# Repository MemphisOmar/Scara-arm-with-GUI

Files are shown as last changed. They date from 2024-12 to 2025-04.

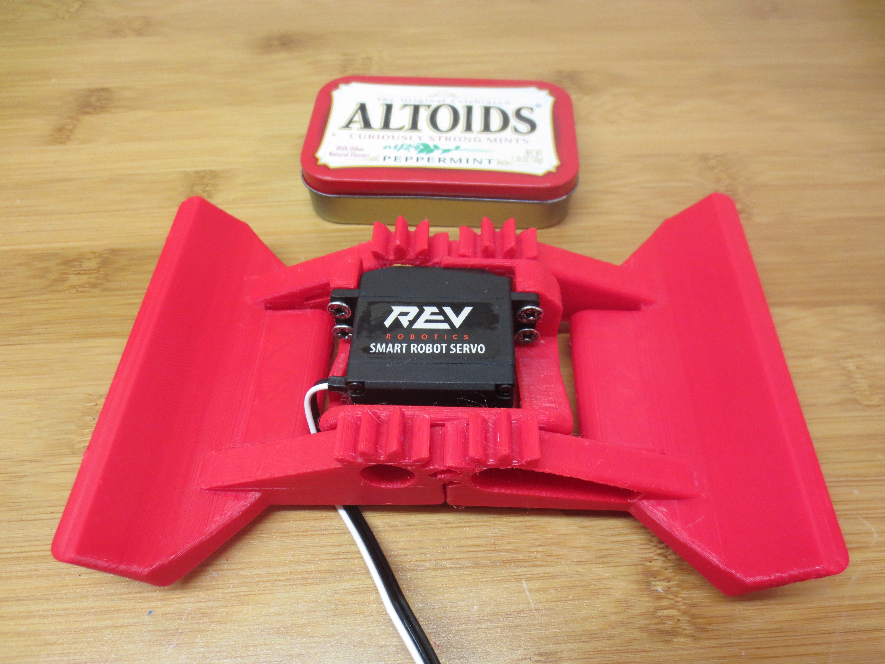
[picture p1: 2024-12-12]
SCARA_CAD/GRIPPER/images/IMG_7482.JPG

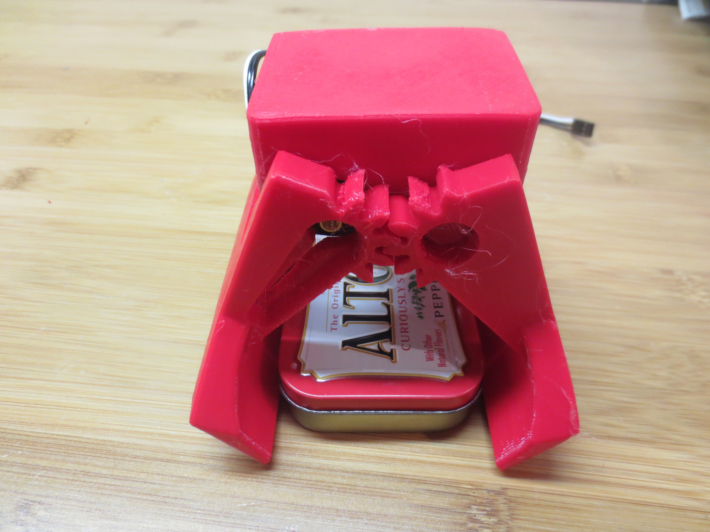
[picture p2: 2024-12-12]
SCARA_CAD/GRIPPER/images/IMG_7483.JPG

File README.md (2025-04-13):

# SCARA Robotic Arm with Graphical Interface

## GRAPHICAL INTERFACE

The graphical interface was programmed in Python using the Flet framework. It is a dynamic interface that communicates with the application via serial communication, displaying real-world changes in the application.

On the left side, the interface features two 2x2 matrices. When a cube is placed in a designated spot within these matrices, the corresponding indicator light for that cube position will illuminate.

The process will automatically pause once both matrices are filled. The operator must then manually restart the process.

A central indicator displays whether the currently detected cube is "Defective" or "Valid". Below this indicator, simple control buttons with essential functions are provided: START, Pause, Continue, and Restart.



## SOLIDWORKS ASSEMBLY



## ASSEMBLED ROBOT

The microcontroller has two initial conditions. The first is the I2C address of the RGB sensor, which is used for the homing procedure.

Once the homing sequence is complete, the graphical interface needs to send a "START" command to initiate the detection process.

The robot's direct kinematics have been solved to allow for individual joint movement in degrees. This facilitates easier access and modification of specific points. The robot is programmed to visit nine key locations: the eight positions corresponding to the cube locations within the two matrices, and one final position on the conveyor belt for placing the valid cubes. To achieve this, the position vectors for each desired location are calculated and stored within the robot's control code.

If a cube is determined to be valid, the robot will retrieve it from the end of the conveyor belt and place it in its designated spot within the matrix. If a cube is defective, the robot will not proceed until the defective cube is removed and a valid cube arrives. This entire process is managed using simple boolean flags within the control logic.




## INTERFACE IN OPERATION




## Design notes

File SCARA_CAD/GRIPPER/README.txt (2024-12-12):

20 kg·cm Robotic Gripper by MechEngineerMike on Thingiverse: https://www.thingiverse.com/thing:3041971

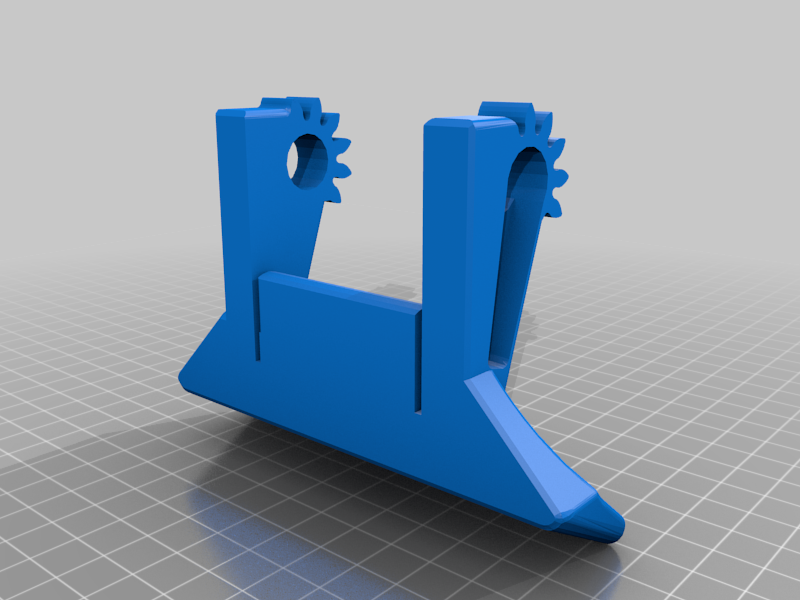
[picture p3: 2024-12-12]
SCARA_CAD/GRIPPER/images/e842a4ac5647148de83dd07140da1f07.png

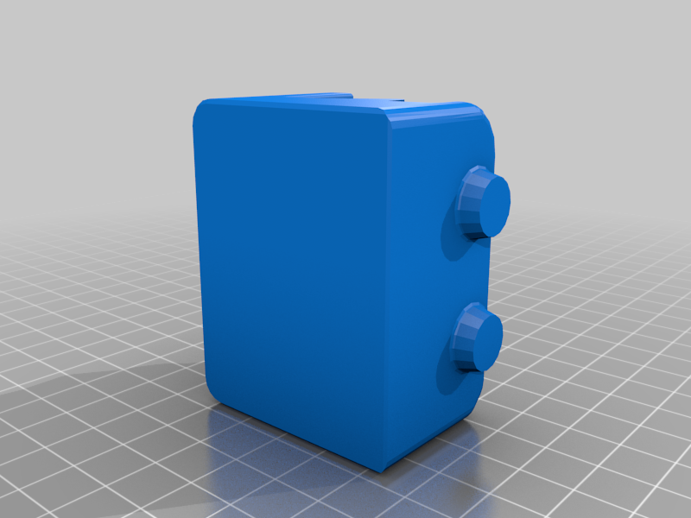
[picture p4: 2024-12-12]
SCARA_CAD/GRIPPER/images/df90dd607aa34544be3c17018d071d21.png

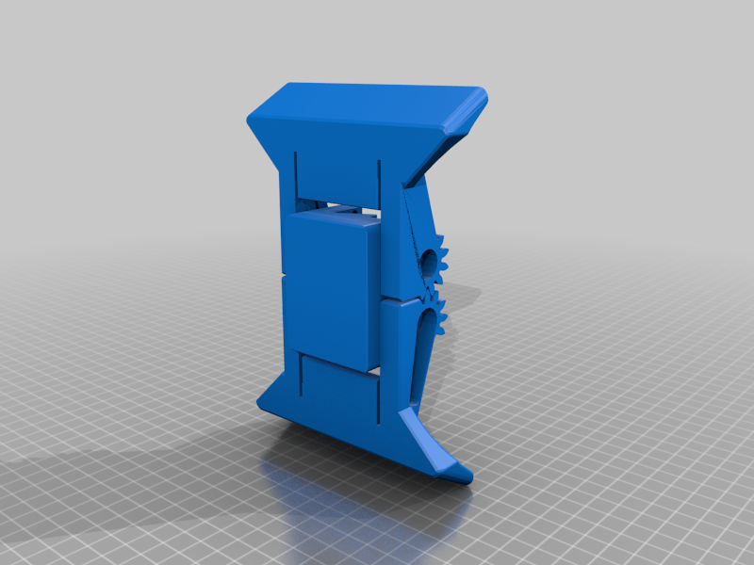
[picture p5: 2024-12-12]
SCARA_CAD/GRIPPER/images/337ccc582f414baa7ae840020906a578.png

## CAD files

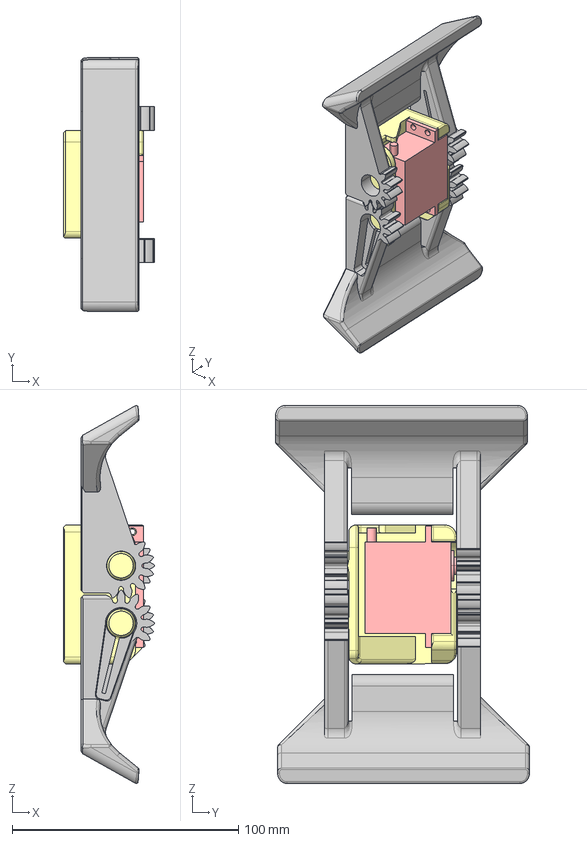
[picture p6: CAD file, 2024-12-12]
SCARA_CAD/GRIPPER/files/Assy_Gripper_20KGcm.stp
40.1 x 112.3 x 167.1 mm
servo_SG90
Arm_Gripper_WIDE x 2
horn.1.1
Gripper_Mount.2

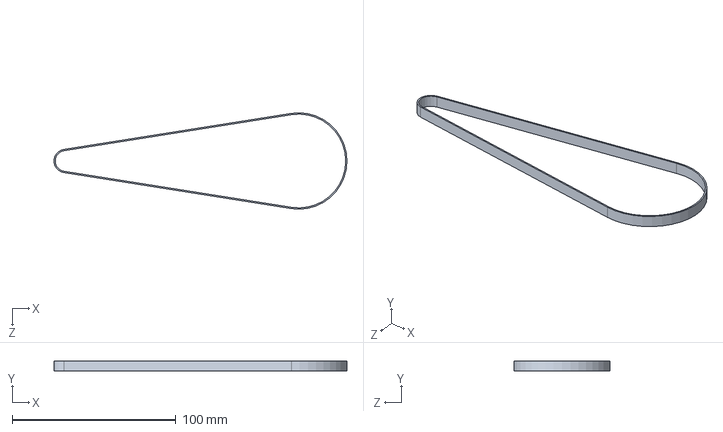
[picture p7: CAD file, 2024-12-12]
SCARA_CAD/GT2 Belt 400mm 2.SLDPRT
179.0 x 6.00 x 58.9 mm

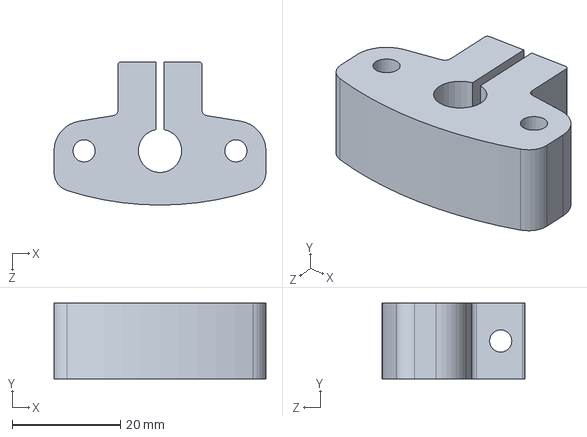
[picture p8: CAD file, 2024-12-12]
SCARA_CAD/11-SOPORTEVARILLA.SLDPRT
39.1 x 14.0 x 26.4 mm

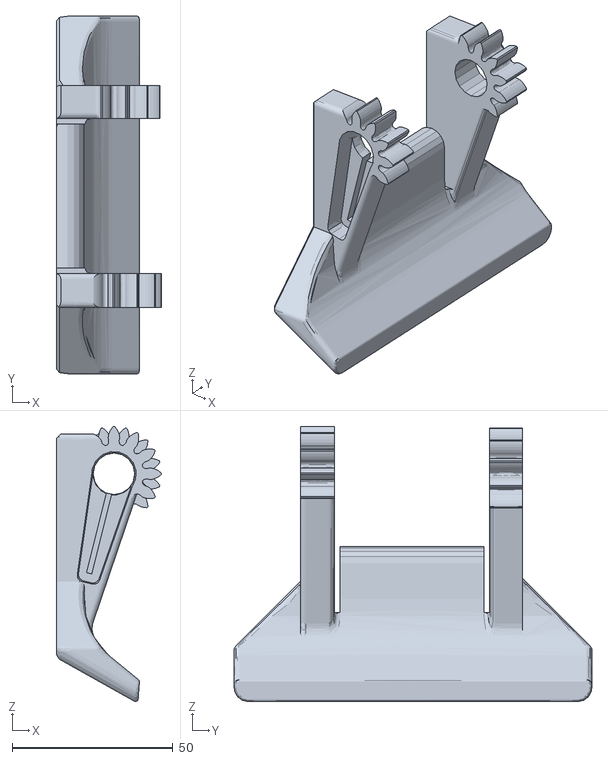
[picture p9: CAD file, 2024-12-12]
SCARA_CAD/GRIPPER/files/Gearheads-gripper-arm.stl
32.5 x 111.4 x 85.5

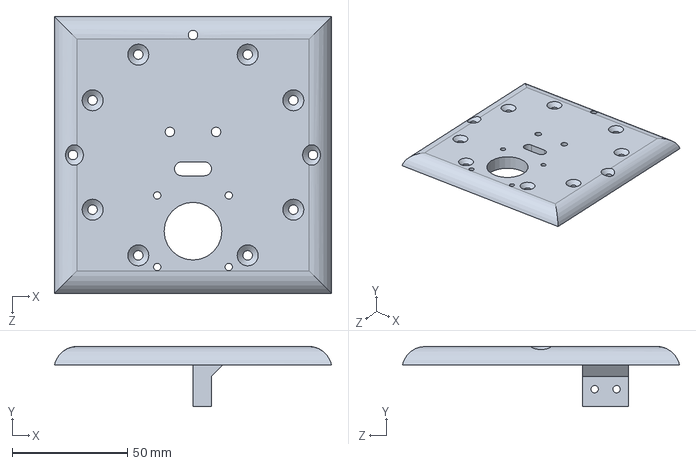
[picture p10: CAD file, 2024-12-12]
SCARA_CAD/10-TOPZ.SLDPRT
120.0 x 26.0 x 120.0 mm

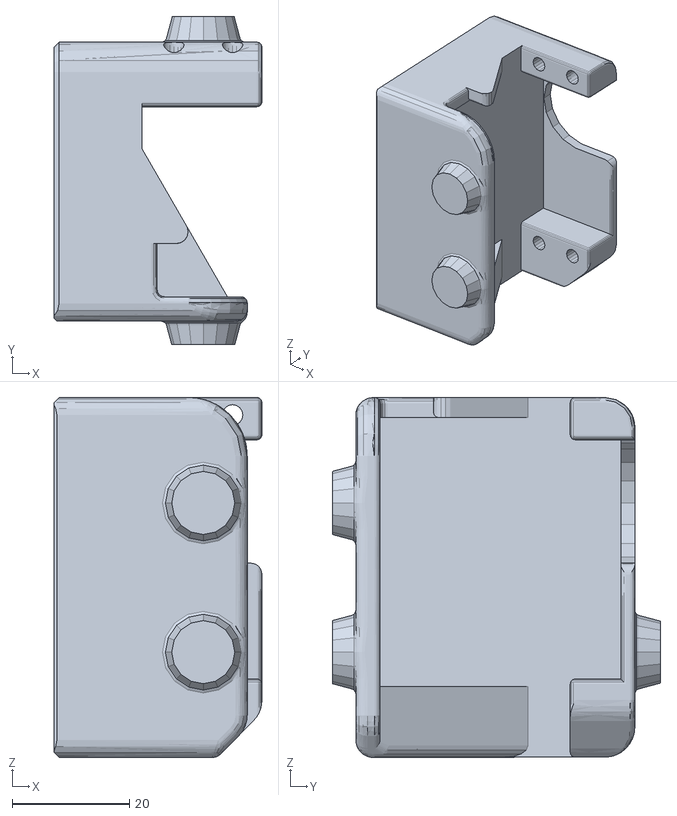
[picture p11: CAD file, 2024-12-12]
SCARA_CAD/GRIPPER/files/gearheads-gripper-mount.stl
35.4 x 56.0 x 61.3

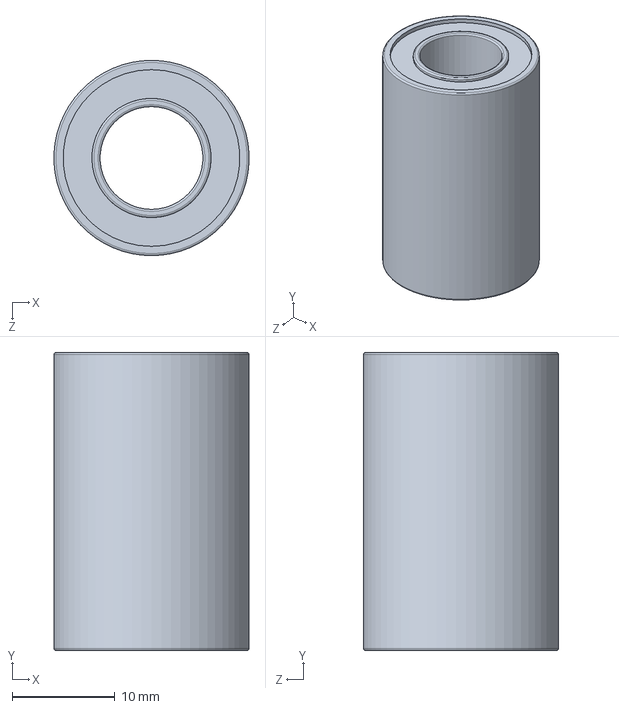
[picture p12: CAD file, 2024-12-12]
SCARA_CAD/Linear Bearing 10x19x29mm.SLDPRT
19.0 x 29.0 x 19.0 mm

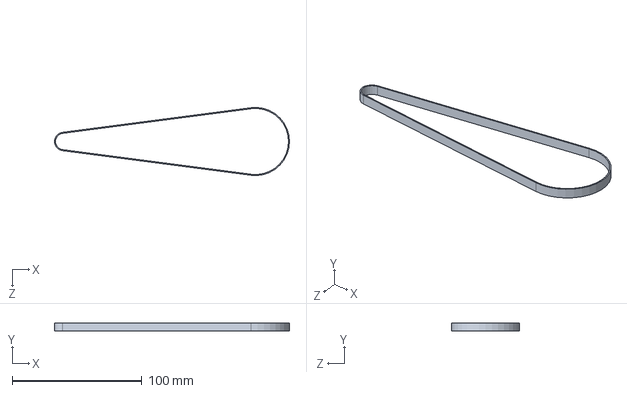
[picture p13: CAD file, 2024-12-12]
SCARA_CAD/GT2 Belt 400mm.SLDPRT
181.4 x 6.00 x 52.5 mm

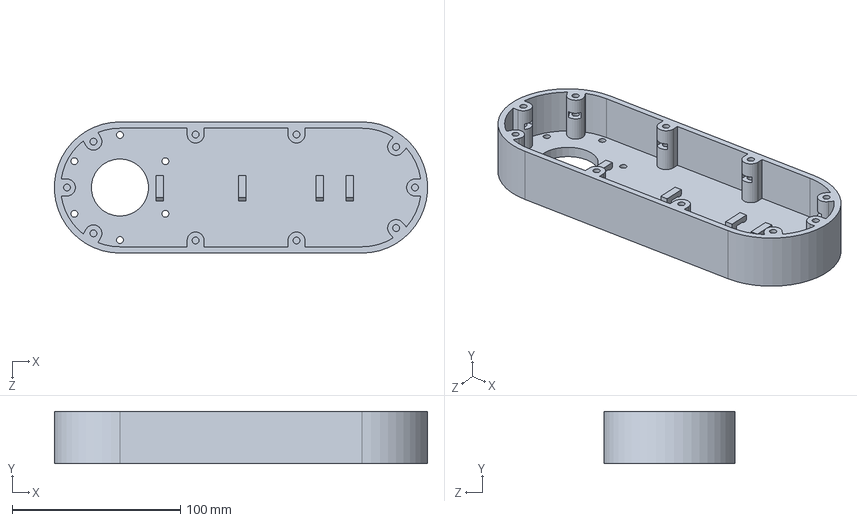
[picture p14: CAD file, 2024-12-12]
SCARA_CAD/6-J2BRZO.SLDPRT
221.8 x 31.0 x 78.0 mm

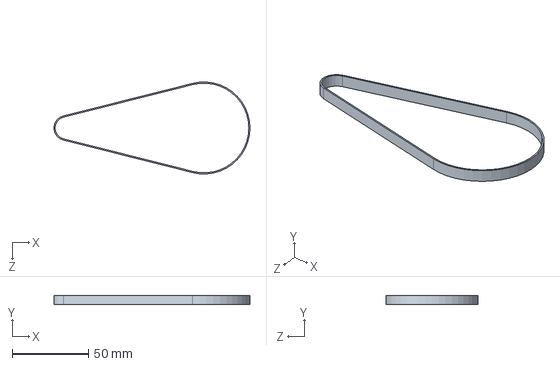
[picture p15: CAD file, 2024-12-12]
SCARA_CAD/GT2 Belt 300mm.SLDPRT
128.1 x 6.00 x 60.1 mm

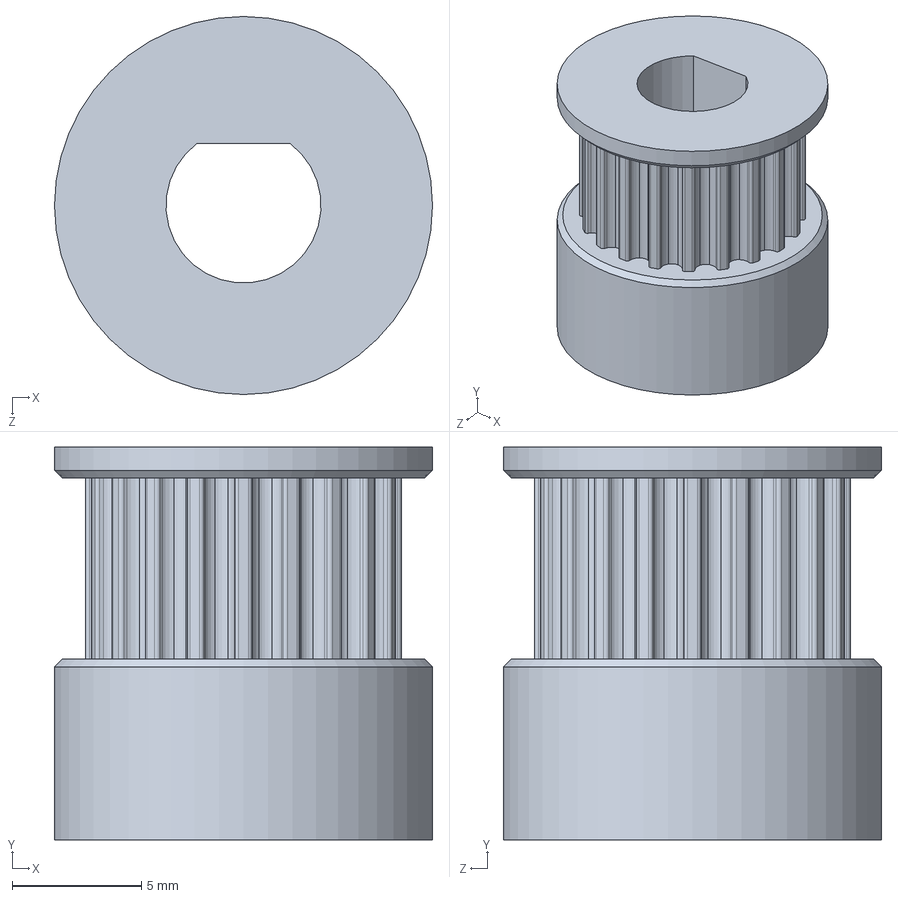
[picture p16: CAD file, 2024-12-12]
SCARA_CAD/GT2 Pulley - Parametric.SLDPRT
14.6 x 15.2 x 14.6 mm

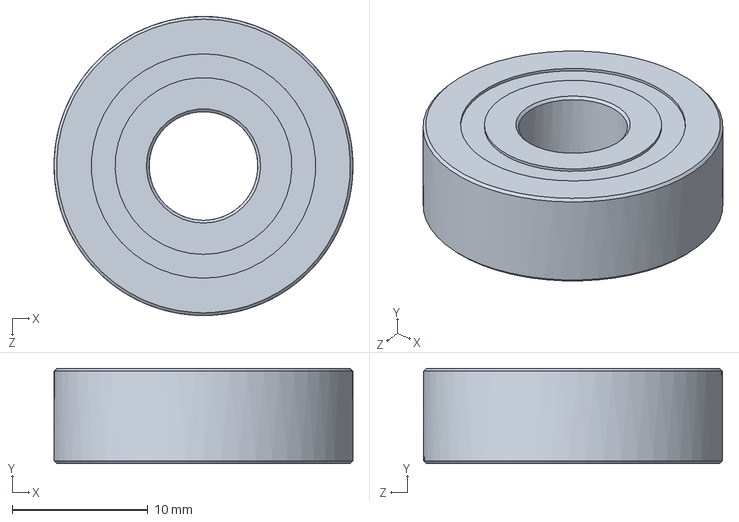
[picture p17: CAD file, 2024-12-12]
SCARA_CAD/Ball Bearing 608 - 8x22x7mm.SLDPRT
22.0 x 7.00 x 22.0 mm

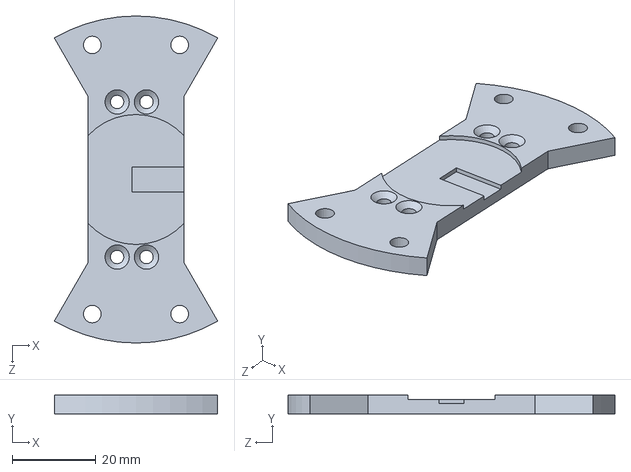
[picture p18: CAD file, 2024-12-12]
SCARA_CAD/9-UNIONPARAJ3.SLDPRT
39.0 x 4.50 x 78.0 mm

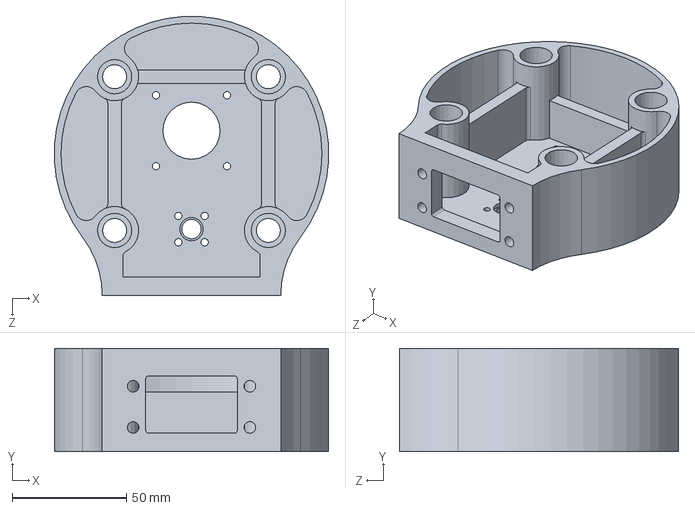
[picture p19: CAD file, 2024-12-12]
SCARA_CAD/3-J1CENTRAL.SLDPRT
119.8 x 45.0 x 121.9 mm

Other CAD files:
SCARA_CAD/Thrust Bearing 35x52x12mm.SLDPRT
SCARA_CAD/Ball Bearing 35x47x7mm.SLDPRT
SCARA_CAD/Micro switch.SLDPRT
SCARA_CAD/Smooth Rod D10mm L400mm.SLDPRT
SCARA_CAD/0-Base.SLDPRT
SCARA_CAD/1-J1 ACOPLEMOD.SLDPRT
SCARA_CAD/2-TapaZ.SLDPRT
SCARA_CAD/4-J1CENTRALBRAZO.SLDPRT
SCARA_CAD/5-COPLEJ1J2.SLDPRT
SCARA_CAD/7-J2TAPABRZO.SLDPRT
SCARA_CAD/8-J3COPLE.SLDPRT
SCARA_CAD/Ball Bearing 30x42x7mm.SLDPRT
SCARA_CAD/GT2 Belt 200mm.SLDPRT
SCARA_CAD/GT2 Belt 300mm 2.SLDPRT
SCARA_CAD/Lead Screw D8mm L380mm.SLDPRT
SCARA_CAD/Lead Screw Nut 8mm.SLDPRT
SCARA_CAD/Stepper NEMA 17 - 20mm shaft.SLDPRT
SCARA_CAD/Thrust Bearing - 40x60x13.SLDPRT
SCARA_CAD/gearheads-gripper-mount.SLDPRT

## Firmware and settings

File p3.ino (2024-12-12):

#include <AccelStepper.h>
#include <Servo.h> ///////////pendiente gripper
#include <math.h>
#include <TimerOne.h>
#include <Wire.h>
#include <Adafruit_TCS34725.h>
Adafruit_TCS34725 tcs = Adafruit_TCS34725(TCS34725_INTEGRATIONTIME_50MS, TCS34725_GAIN_4X);
unsigned long previousMillis = 0; // Para almacenar el último tiempo en que se ejecutó printVal
const long interval = 1000;
#define limitSwitch1 11
#define limitSwitch2 10
#define limitSwitch3 A3
#define limitSwitch4 9

#define motorPin1 36
#define motorPin2 37
#define sensorInicial 45
#define sensorFinal 47
#define servoPin 49
AccelStepper stepper1(1, 2, 5); // (driver, STEP, DIR)
AccelStepper stepper2(1, 3, 6);
AccelStepper stepper3(1, 4, 7); //////// PENDIENTE GRIPPER
AccelStepper stepper4(1, 12, 13);
Servo gripperServo; 
Servo conveyorServo;

// Puntos en grados
int conveyorBeltPosition[4] = {10, 23, 0, 120}; // Banda transportadora en grados
const int numPoints = 8;
int points[numPoints][4] = {
  {0, 105, 0, 85}, // Punto 1 en grados
  {4, 115, 0, 85}, // Punto 2 en grados
  {-10, 130, 0, 85}, // Punto 3 en grados
  {-8, 115, 0, 85}, // Punto 4 en grados
  {0, 105, 0, 100}, // Punto 5 en grados
  {4, 115, 0, 100}, // Punto 6 en grados
  {-10, 130, 0, 100}, // Punto 7 en grados
  {-8, 115, 0, 100}  // Punto 8 en grados
};

double x = 10.0;
double y = 10.0;
double L1 = 228; // L1 = 228mm
double L2 = 136.5; // L2 = 136.5mm
double theta1, theta2, phi, z;

int stepper1Position, stepper2Position, stepper3Position, stepper4Position;

const float theta1AngleToSteps = 44.444444;
const float theta2AngleToSteps = 35.555555;
const float phiAngleToSteps = 10;
const float zDistanceToSteps = 100;

byte inputValue[5];
int k = 0;
bool paused = false;
bool startCommandReceived = false;
bool stopCommandReceived = false;
String content = "";
int data[10];

int theta1Array[100];
int theta2Array[100];
int phiArray[100];
int zArray[100];
int gripperArray[100];
int positionsCounter = 0;

volatile bool OBJVAL = false;
volatile bool toggle = false; // Declarar toggle como variable global

void setup() {
  Serial.begin(115200);

  if (tcs.begin()) {
    Serial.println("Sensor TCS34725 iniciado correctamente.");
  } else {
    Serial.println("Error al iniciar el sensor TCS34725. Verifique la conexión.");
    while (1); // Detener el programa si no se puede iniciar el sensor
  }

  pinMode(limitSwitch1, INPUT_PULLUP);
  pinMode(limitSwitch2, INPUT_PULLUP);
  pinMode(limitSwitch3, INPUT_PULLUP);
  pinMode(limitSwitch4, INPUT_PULLUP);

  // Stepper motors max speed
  stepper1.setMaxSpeed(4000);
  stepper1.setAcceleration(2000);
  stepper2.setMaxSpeed(4000);
  stepper2.setAcceleration(2000);
  stepper3.setMaxSpeed(4000);
  stepper3.setAcceleration(2000);
  stepper4.setMaxSpeed(4000);
  stepper4.setAcceleration(2000);
  
  gripperServo.attach(53, 600, 2500);
  data[6] = 100;
  gripperServo.write(data[6]);
  conveyorServo.write(180); // Posición inicial del servo


  delay(1000);
  data[5] = 100;
  homing();


  digitalWrite(motorPin1, HIGH);
  digitalWrite(motorPin2, LOW);
}

void loop() {
   static unsigned long lastSensorReadTime = 0;
  const unsigned long sensorReadInterval = 1000;
  motorAdelante();
  // Esperar el comando "START" para iniciar
  if (!startCommandReceived || stopCommandReceived) {
    if (Serial.available() > 0) {
      String command = Serial.readStringUntil('\n');
      command.trim();
      if (command == "START") {
        startCommandReceived = true;
        stopCommandReceived = false;
        Serial.println("SISTEMA INICIADO");
      } else if (command == "STOP") {
        startCommandReceived = false;
        stopCommandReceived = true;
        Serial.println("SISTEMA DETENIDO");
      }
    }
    return; // No hacer nada hasta recibir el comando "START"
  }

  // Leer valores del sensor RGB periódicamente
  if (millis() - lastSensorReadTime >= sensorReadInterval) {
    lastSensorReadTime = millis();
    uint16_t r, g, b, c;
    tcs.getRawData(&r, &g, &b, &c);

    // Normalizar los valores RGB
    float sum = r + g + b;
    float red = r / sum;
    float green = g / sum;

    // Clasificar el color
    if (red > green && red > 0.45) {
      Serial.println("DEF");
      OBJVAL = false;
      conveyorServo.write(125); // Activar el servo para el cubo defectuoso
    } else if (green > red && green > 0.45) {
      Serial.println("VAL");
      conveyorServo.write(180); // Activar el servo para el cubo defectuoso
      OBJVAL = true;
    }
  }

  // Resto del código del bucle
  for (int i = 0; i < numPoints; i++) {
    // Esperar a que OBJVAL sea true para procesar el cubo
    while (!OBJVAL) {
      // Leer valores del sensor RGB periódicamente
      if (millis() - lastSensorReadTime >= sensorReadInterval) {
        lastSensorReadTime = millis();
        uint16_t r, g, b, c;
        tcs.getRawData(&r, &g, &b, &c);

        // Normalizar los valores RGB
        float sum = r + g + b;
        float red = r / sum;
        float green = g / sum;

        // Clasificar el color
        if (red > green && red > 0.45) {
          Serial.println("DEF");
          OBJVAL = false;
          conveyorServo.write(180); // Activar el servo para el cubo defectuoso
        } else if (green > red && green > 0.45) {
          Serial.println("VAL");
          OBJVAL = true;
          conveyorServo.write(125); // Activar el servo para el cubo defectuoso
        }
      }
      delay(100); // Espera un poco antes de verificar nuevamente
    }

    // Mover a la banda transportadora
    moveToPosition(conveyorBeltPosition);
    delay(1000); // Espera un segundo antes de tomar el cubo

    // Simular la acción de tomar el cubo
    gripperServo.write(180); // Cerrar el gripper
    delay(500); // Espera medio segundo para asegurar que el cubo está tomado
    moveToSafeZ();
    delay(100);
    // Mover al punto de destino
    moveToPosition(points[i]);
    delay(1000); 
    gripperServo.write(90); // Abrir el gripper
    delay(500); 
    Serial.print("P");
    Serial.println(i + 1);

    // Cambiar la bandera a false después de procesar el cubo
    OBJVAL = false;
    moveToSafeZ();
    delay(100);
    // Verificar si se debe pausar
    while (paused) {
      if (Serial.available() > 0) {
        String command = Serial.readStringUntil('\n');
        command.trim();
        if (command.equals("CONTINUAR")) {
          paused = false;
          Serial.println("CONTINUAO");
        }
      }
    }

    // Verificar si se debe pausar después de cada punto
    if (Serial.available() > 0) {
      String command = Serial.readStringUntil('\n');
      command.trim();
      if (command.equals("PAUSAR")) {
        paused = true;
        Serial.println("PAUSAO");
      }
    }
  }

  // Pausar al llegar al último punto y esperar el comando "REINICIAR"
  while (true) {
    if (Serial.available() > 0) {
      String command = Serial.readStringUntil('\n');
      command.trim();
      if (command.equals("REINICIAR")) {
        break;
      }
    }
  }
}

void moveToPosition(int point[4]) {
  stepper1.moveTo(point[0] * theta1AngleToSteps);
  stepper2.moveTo(point[1] * theta2AngleToSteps);
  stepper3.moveTo(point[2] * phiAngleToSteps);
  stepper4.moveTo(point[3] * zDistanceToSteps);

  while (stepper1.distanceToGo() != 0 || 
         stepper2.distanceToGo() != 0 || 
         stepper3.distanceToGo() != 0 || 
         stepper4.distanceToGo() != 0) {
    stepper1.run();
    stepper2.run();
    stepper3.run();
    stepper4.run();
  }
}

void serialFlush() {
  while (Serial.available() > 0) {
    Serial.read();
  }
}

void moveToSafeZ() {
  stepper4.moveTo(165 * zDistanceToSteps);
  while (stepper4.distanceToGo() != 0) {
    stepper4.run();
  }
}

void homing() {
  // Homing Stepper4
  while (digitalRead(limitSwitch4) != 0) {
    stepper4.setSpeed(1500);
    stepper4.runSpeed();
    stepper4.setCurrentPosition(17000); // When limit switch pressed set position to 0 steps
  }
  delay(20);
  stepper4.moveTo(16500);
  while (stepper4.currentPosition() !=16500) {
    stepper4.run();
  }

  stepper3.moveTo(0);
  while (stepper3.currentPosition() != 0) {
    stepper3.run();
  }

  // Homing Stepper2
  while (digitalRead(limitSwitch2) != 0) {
    stepper2.setSpeed(-1300);
    stepper2.runSpeed();
    stepper2.setCurrentPosition(-5420); // When limit switch pressed set position to -5440 steps
  }
  delay(20);

  stepper2.moveTo(0);
  while (stepper2.currentPosition() != 0) {
    stepper2.run();
  }

  // Homing Stepper1
  while (digitalRead(limitSwitch1) != 0) {
    stepper1.setSpeed(-1200);
    stepper1.runSpeed();
    stepper1.setCurrentPosition(-3955); // When limit switch pressed set position to 0 steps
  }
  delay(20);
  stepper1.moveTo(0);
  while (stepper1.currentPosition() != 0) {
    stepper1.run();
  }
}




void motorAdelante() {
  digitalWrite(motorPin1, HIGH);
  digitalWrite(motorPin2, LOW);
}

void motorParar() {
  digitalWrite(motorPin1, LOW);
  digitalWrite(motorPin2, LOW);
}

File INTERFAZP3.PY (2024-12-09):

import flet as ft
import serial
import threading

# Configuración del puerto serial
ser = serial.Serial('COM3', 115200, timeout=1)  # Añadir timeout para evitar bloqueos

# Función para leer datos del puerto serial
def read_serial(leds, text_display, pause_button, reiniciar_button, led_indicator, start_button, status_led):
    while True:
        if ser.in_waiting > 0:
            data = ser.readline().decode('utf-8').strip()
            print(f"Received: {data}")  # Mensaje de depuración
            text_display.value = data
            text_display.update()
            if data == "REINICIAR":
                for led in leds:
                    led.bgcolor = ft.colors.BLACK
                    led.update()
            elif data.startswith("P") and data[1:].isdigit():
                index = int(data[1]) - 1
                if 0 <= index < len(leds):
                    leds[index].bgcolor = ft.colors.GREEN
                    leds[index].update()
            elif data == "PAUSAO":
                pause_button.text = "CONTINUAR"
                led_indicator.bgcolor = ft.colors.RED
                pause_button.update()
                led_indicator.update()
            elif data == "CONTINUAO":
                pause_button.text = "PAUSAR"
                led_indicator.bgcolor = ft.colors.GREEN
                pause_button.update()
                led_indicator.update()
            elif data == "VAL":
                print("VAL received")  # Mensaje de depuración
                status_led.bgcolor = ft.colors.GREEN
                status_led.content = ft.Text("VALIDO", color=ft.colors.WHITE, size=60)  # Ajustar el tamaño del texto
                status_led.update()
            elif data == "DEF":
                print("DEF received")  # Mensaje de depuración
                status_led.bgcolor = ft.colors.RED
                status_led.content = ft.Text("DEFECTUOSO", color=ft.colors.WHITE, size=60)  # Ajustar el tamaño del texto
                status_led.update()
            
            # Verificar si todos los LEDs están encendidos
            all_on = all(led.bgcolor == ft.colors.GREEN for led in leds)
            reiniciar_button.disabled = not all_on
            reiniciar_button.update()

# Función para enviar datos al puerto serial
def send_serial(e, text_input):
    ser.write(text_input.value.encode('utf-8'))
    ser.flush()  # Asegurarse de que los datos se envían inmediatamente
    text_input.value = ""
    text_input.update()

def start_button_click(e, start_button, start_led):
    ser.write("START".encode('utf-8'))
    ser.flush()  # Asegurarse de que los datos se envían inmediatamente
    start_button.disabled = True
    start_button.update()
    start_led.bgcolor = ft.colors.GREEN
    start_led.update()

# Función para enviar la palabra "REINICIAR" al puerto serial y apagar los LEDs
def send_reiniciar(e, leds):
    if all(led.bgcolor == ft.colors.GREEN for led in leds):
        ser.write("REINICIAR".encode('utf-8'))
        ser.flush()  # Asegurarse de que los datos se envían inmediatamente
        for led in leds:
            led.bgcolor = ft.colors.BLACK
            led.update()

# Función para manejar el botón de pausa/continuar
def toggle_pause(e, pause_button, led_indicator):
    if pause_button.text == "PAUSAR":
        ser.write("PAUSAR".encode('utf-8'))
        ser.flush()  # Asegurarse de que los datos se envían inmediatamente
        pause_button.text = "CONTINUAR"
        led_indicator.bgcolor = ft.colors.RED
    else:
        ser.write("CONTINUAR".encode('utf-8'))
        ser.flush()  # Asegurarse de que los datos se envían inmediatamente
        pause_button.text = "PAUSAR"
        led_indicator.bgcolor = ft.colors.GREEN
    pause_button.update()
    led_indicator.update()

# Función para enviar "VAL" al puerto serial
def send_val(e):
    print("Sending VAL")  # Mensaje de depuración
    ser.write("VAL".encode('utf-8'))
    ser.flush()  # Asegurarse de que los datos se envían inmediatamente

# Función para enviar "DEF" al puerto serial
def send_def(e):
    print("Sending DEF")  # Mensaje de depuración
    ser.write("DEF".encode('utf-8'))
    ser.flush()  # Asegurarse de que los datos se envían inmediatamente

# Crear la interfaz
def main(page):
    page.window_width = 1920
    page.window_height = 1080
    page.vertical_alignment = ft.MainAxisAlignment.CENTER

    leds = [ft.Container(width=100, height=100, bgcolor=ft.colors.BLACK) for _ in range(8)]  # Doble de tamaño
    
    led_grid_1 = ft.Column([
        ft.Row([leds[0], leds[1]], spacing=10),
        ft.Row([leds[2], leds[3]], spacing=10),
        ft.Text("Malla 1")
    ], spacing=10)

    led_grid_2 = ft.Column([
        ft.Row([leds[4], leds[5]], spacing=10),
        ft.Row([leds[6], leds[7]], spacing=10),
        ft.Text("Malla 2")
    ], spacing=10)


    text_display = ft.Text(value="", size=20)
    text_input = ft.TextField(label="Enviar al serial", on_submit=lambda e: send_serial(e, text_input))
    reiniciar_button = ft.ElevatedButton(text="REINICIAR", on_click=lambda e: send_reiniciar(e, leds), disabled=True, width=200, height=100)
    pause_button = ft.ElevatedButton(text="PAUSAR", bgcolor=ft.colors.YELLOW, color=ft.colors.BLACK, on_click=lambda e: toggle_pause(e, pause_button, led_indicator), width=200, height=100)
    led_indicator = ft.Container(width=200, height=100, bgcolor=ft.colors.GREEN)  # Ajustar el ancho del indicador
    start_led = ft.Container(width=200, height=100, bgcolor=ft.colors.BLACK)
    start_button = ft.ElevatedButton(text="START", on_click=lambda e: start_button_click(e, start_button, start_led), width=200, height=100)
    
    # Nuevo LED de estado
    status_led = ft.Container(width=600, height=300, bgcolor=ft.colors.WHITE, content=ft.Text("", size=60))  # Triplicar el tamaño
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

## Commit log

2024-12-09 SENSOR RGB FUNCIONAL
    SENSOR RGB ES FUNCIONAL
2024-12-11 PUNTOS ACTUALIZADOS
    PUNTOS ACTUALIZADOS, PUNTO SEGURO, NUEVA UBICACION AL SERVO
2024-12-12 VERSION FINAL
    Version Final para color sorting, está preparado para mejorar la banda transportadora, la ubicacion de la banda tranpsortadora ha sido mejorada, así como incluir la estructura para posteriormente aña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
2024-12-12 ARCHIVOS CAD PARA EL BRAZO
    [0-Base.SLDPRT, 01-ENGRANEGT2J122-80.SLDPRT, 02-ENGRANEGT2J1BASE110.SLDPRT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]
2024-12-12 GRIPPER BRAZO
    [Assy_Gripper_20KGcm.stp, Gearheads-gripper-arm.stl, gearheads-gripper-mount.stl]
